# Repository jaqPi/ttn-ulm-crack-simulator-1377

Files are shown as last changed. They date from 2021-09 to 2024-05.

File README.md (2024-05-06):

# ttn-ulm-crack-simulator-1377

Experimental setup to benchmark various _VL6180X_ distance sensors. The VL6180X by _STMicroelectronics_ is a time-of-flight (ToF) distance and ambient light (ALS) sensor. It measures the time a laser takes from the sensor to a reflecting target and back to the sensor. It has an optimal operating range from 0 - 10 cm with a resolution of 1 mm (up to 60 cm with decreased resolution) and an accuracy of +/- 1 mm. For more details, please refer to the [datasheet](https://www.st.com/en/imaging-and-photonics-solutions/vl6180x.html#documentation).

## Terms

The following terms are used in the course of this document:

| Term | Explanation |
| --- | --- |
| Sensor | A term that that is used for several different things. In the strict definition, it describes that piece of hardware that is capable of measuring something. A sensor can measure one or many information about its environment. In our case, the actual sensor is the VL6180X.  It can measures a distance between itself and a reflector or obstacle. Furthermore, it is capable of measuring its ambient light conditions. **BUT:** In its broader meaning (especially in the context of Arduino-like microcontrollers), sensor does not only describe that sensing piece of hardware, but also the package of required electrical components that the sensor is connected to. That package is actually called **breakout board** but can also be referred to as sensor. In the following, we will refer to the breakout boards as sensor. |
| Breakout Board | Package of several required electrical components and the actual sensor. Shipped by an integrator (e.g., Pololu and Adafruit) |
| Actual Distance | Real distance between reflector and sensor |
| Measured Distance | Distance between sensor and reflector as measured by a sensor (will vary)
| Sample error | Each sensor is different. Therefore, measuring the exact thing with two sensors of the same type will result in more or less different measurements. The delta is called sample error. |
| Microcontroller (uC) | Same as _sensor_. In the strict sense, uC describes a processing unit. But in the broader (our) sense, uC describes a uC mounted on a board along with several electrical components required for an easy experimentation in the context of Arduino and Co. |

## Goal

Since the speed of light in a medium depends on the density of that medium, the measured distance varies depending on the following environmental factors:

1. Ambient Light
1. Temperature
1. Relative Humidity
1. Air Pressure

Moreover, the measured distance will be affected by further parameters we now, such as ambient light or voltage drift of the power supply, but even worse, there are some factors, we have not considered. Consequently, we assume, that it is more goal-oriented to collect many measurements under different environment conditions but with the same actual distance to derive a mathematical model. The model to be developed should take the environmental factors as listed above as well as the ambient light and measured distance as inputs, and should return a distance that is as close as possible the actual distance.

### Notes

1. We exclude the effect of the reflectance of the reflector. Regarding the datasheet, we chose a light grey piece of aluminum.
1. We further exclude the effect of a varying voltage. In our experiment, we use a power supply (instead of a battery) that always ensures the same voltage.
1. To minimize the impact of a broken sensor or sample error, we use two BME280 and four VL6180X from two different integrators.
1. The VL6180X sensor offers an accuracy of +/-1 mm and a resolution of 1 mm. Nevertheless, we assume, that with a sufficient amount of measurements, the measured distance converges to the actual distance.

## Setup

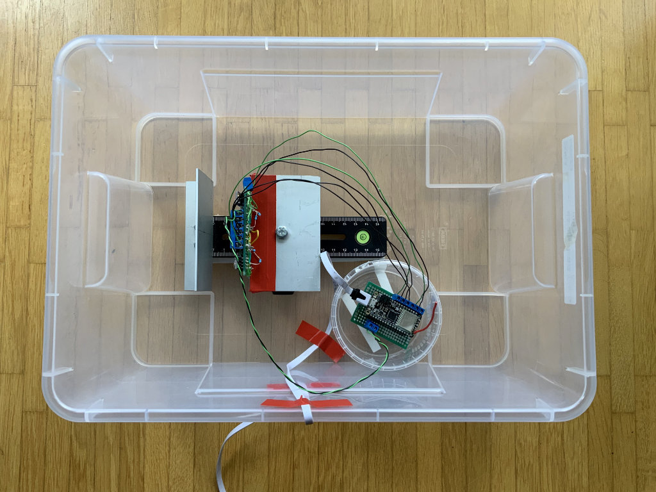
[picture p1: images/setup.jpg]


All sensors are soldered to a perfboard which is mounted on top of a rail slider. The slider can be fixed at any position along the rail. The reflector is screwed at one side of the rail and can not be moved.

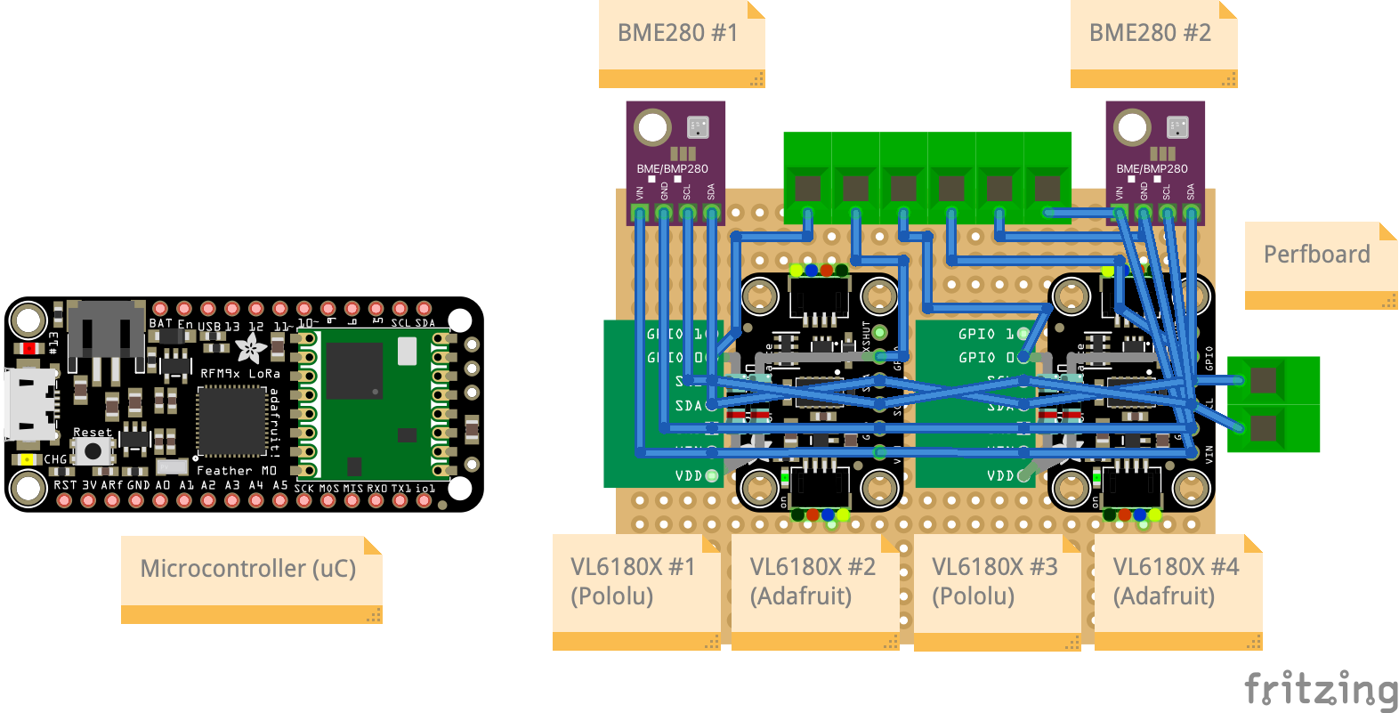
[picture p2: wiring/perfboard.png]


Sensors used and their sensing capabilities:

* 2x Pololu VL6180X (Distance, ambient light)
* 2x Adafruit VL6180X (distance, ambient light)
* 2x BME280 AliExpress (temperature, humidity, air pressure)

To start an experiment, the slider must be fixed to an arbitrary position.

## Program Flow

```mermaid
graph TD
    A[Start] --> B[Init Sensors];
    B --> |i=1|C[Measurement BME280 #i];
    C --> D{i < 2?};
    D --> |true / i+=1|C;
    D --> |false / d=1|E[Measurement VL6180X #i];
    E --> F{d < 4?};
    F --> |true / d+=1|E;
    F --> |false|G[Send data packets one by one];
    G --> H[Sleep]
    H --> |after 15 min / i=1|C;
```

As it can be seen, the measurements are taken sequentially. In other words, in theory, there may be a variation in the environment conditions between the single measurements. However, since a single measurement of a VL6180X takes around 5 s (BME280 < 1 s), we assume, that this variation can be ignored.

### Measurement

In case of the VL6180X measurements (distance and ambient light), each value is calculated on the basis of a series of 50 single measurements. Based on these 50 single values, we calculate the mean, standard derivation, and median at the uC.

In case of the BME280 measurements (temperature, air pressure, humidity), the values are read a single time from the sensor and not further processed.

### Data Transmission

Due to packet size restrictions by the LMiC library (max 53 Byte / Packet), the measured data is sent separately per sensor. The packets are queued and sent after all measurements are taken. Consequently, the transmission does not delay the measurements.

The sent data packets are received by a server and stored in a database.

## Payload Format

Per measurement iteration (consisting of two BME280 measurements and four VL6180X measurements) the uC sends five packets: a packet containing environmental data and four packets containing distance data.

## Environment Packet

First packet sent by uC.

| Name | Unit | Description |
| --- | --- | --- |
| temp1 | °C | Temperature measured by BME280 #1 |
| pressure1 | hPa | Atmospheric pressure measured by BME280 #1 |
| humidity1 | % | Relative humidity measured by BME280 #1 |
| temp2 | °C | Temperature measured by BME280 #2 |
| pressure2 | hPa | Atmospheric pressure measured by BME280 #2 |
| humidity2 | % | Relative humidity measured by BME280 #2 |

## Distance and Ambient Light (ALS) Packet

There are four VL6180X ToF distance sensors connected to the uC. Two manufactured by Pololu (#1+2) and two by Adafruit (#3+4).

| Name | Unit | Description |
| --- | --- | --- |
| meanDistanceX | mm | Mean of 50 x distance measurements |
| standardDeviationDistanceX | mm | Standard deviation of 50 x distance measurements |
| medianDistanceX | mm | Median of 50 x distance measurements |
| successfulMeasurementsDistance | - | If a single measurement times out, it is excluded from the values above. Remainder: a series consists of 50 measurements. Hence, the max value is 50. If value is below 50, value might not be reliable. |
| meanAmbientLightX | ? | Mean of 50 x ALS measurements |
| standardDeviationAmbientLightX | ? | Standard deviation of 50 x ALS measurements |
| medianAmbientLightX | ? | Median of 50 x ALS measurements |
| successfulMeasurementsAmbientLightX | - | If a single measurement times out, it is excluded from the values above. Remainder: a series consists of 50 measurements. Hence, the max value is 50. If value is below 50, value might not be reliable. |

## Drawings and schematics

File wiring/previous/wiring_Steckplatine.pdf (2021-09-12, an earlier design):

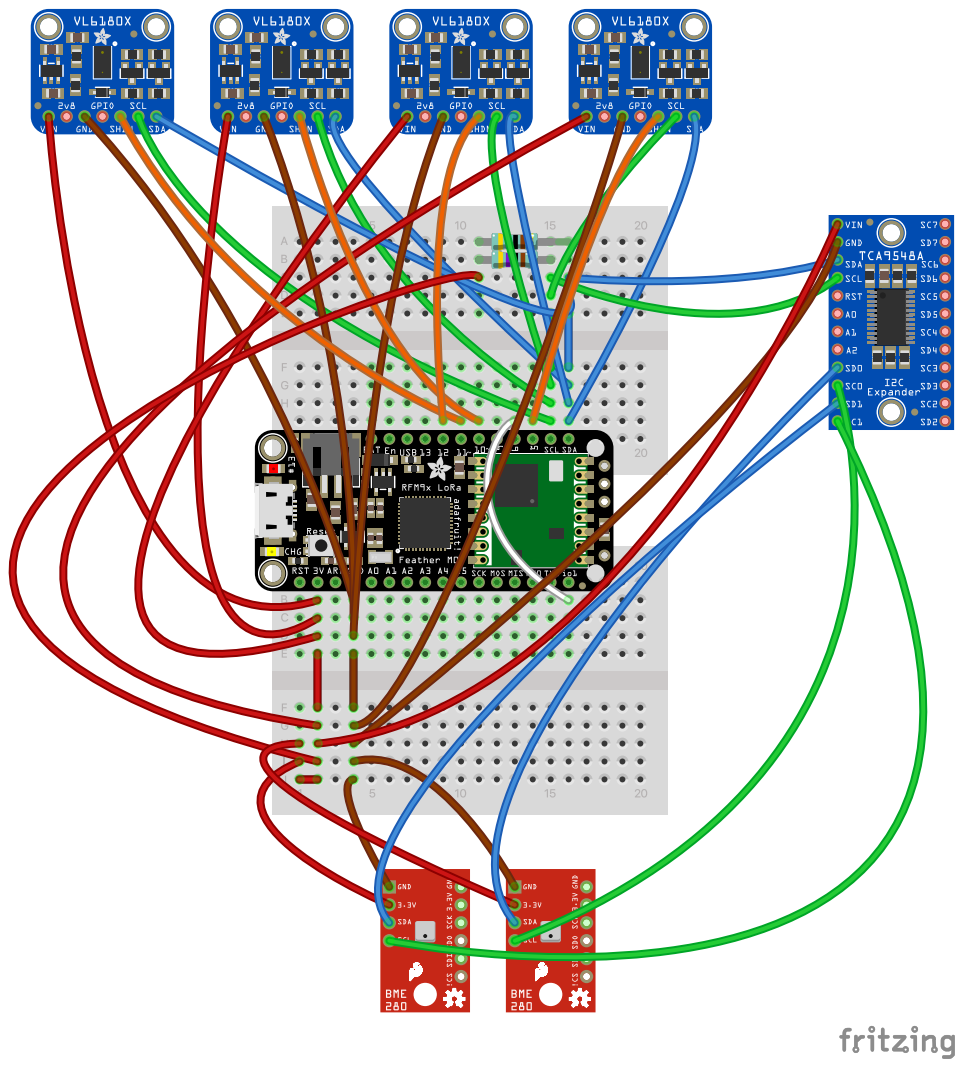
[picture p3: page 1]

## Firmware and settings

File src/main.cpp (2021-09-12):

/*
Code is based on the the OTAA example of the arduino-lmic library

 * Copyright (c) 2015 Thomas Telkamp and Matthijs Kooijman
 * Copyright (c) 2018 Terry Moore, MCCI

which is licensed under the MIT license
https://github.com/mcci-catena/arduino-lmic/blob/master/examples/ttn-otaa/ttn-otaa.ino
*/


#include <Arduino.h>
#include <SPI.h>
#include <Wire.h>
#include <VL6180X.h>
#include <Adafruit_Sensor.h>
#include <Adafruit_BME280.h>
#include "measurements.h"
#include "sensors.h"
#include <Statistics.h>
#include "arduino_lmic.h"
#include <hal/hal.h>
#include <Queue.h>

#include <Credentials.h> // TODO

VL6180X adafruitsensor1;
#define PIN_RESET_ADAFRUIT_1 10
VL6180X pololusensor1;
#define PIN_RESET_POLOLU_1 11
VL6180X adafruitsensor2;
#define PIN_RESET_ADAFRUIT_2 12
VL6180X pololusensor2;
#define PIN_RESET_POLOLU_2 5



const uint8_t numberOfMeasurements = 50; // max 255!

enum MESSAGE_TYPE {
  TEMPS,
  SENSOR1,
  SENSOR2,
  SENSOR3,
  SENSOR4,
  ERROR
};

enum ERROR_CODES {
  NO_RESPONSE_I2C_ADDRESS,
  DEFAULT_I2C,
  NO_RESPONSE_SENSOR,
  SENSOR_ERROR
};

typedef struct LoRaPacket {
    byte payload[20];
    uint8_t length;
} loRaPacket_t;

Queue<loRaPacket_t> queue = Queue<loRaPacket_t>(5);

Adafruit_BME280 bme1;
Adafruit_BME280 bme2;

// Initially the same config for all sensors
const SensorConfig configInterleaved = { INTERLEAVED, MANUAL, 30, 50, 500};
const SensorConfig configOneByOne = { ONE_BY_ONE, MANUAL, 30, 50, 500};

const TofSensor tofSensors[4] = {
  TofSensor { adafruitsensor1, configInterleaved, PIN_RESET_ADAFRUIT_1, 0x25 },
  TofSensor { pololusensor1,   configInterleaved, PIN_RESET_POLOLU_1,   0x26 },
  TofSensor { adafruitsensor2, configInterleaved, PIN_RESET_ADAFRUIT_2, 0x27 },
  TofSensor { pololusensor2,   configInterleaved, PIN_RESET_POLOLU_2,   0x28 }
};

const uint8_t numberOfSensors = sizeof(tofSensors) / sizeof(TofSensor);




void os_getArtEui (u1_t* buf) { memcpy_P(buf, APPEUI, 8);}
void os_getDevEui (u1_t* buf) { memcpy_P(buf, DEVEUI, 8);}
void os_getDevKey (u1_t* buf) {  memcpy_P(buf, APPKEY, 16);}



static osjob_t sendjob;

const unsigned TX_INTERVAL = 12*60; // in seconds


// Pin mapping
// Pin mapping for Adafruit Feather M0 LoRa
const lmic_pinmap lmic_pins = {
    .nss = 8,
    .rxtx = LMIC_UNUSED_PIN,
    .rst = 4,
    .dio = {3, 6, LMIC_UNUSED_PIN},
    .rxtx_rx_active = 0,
    .rssi_cal = 8,              // LBT cal for the Adafruit Feather M0 LoRa, in dB
    .spi_freq = 8000000,
};



void scanI2C() {
  Serial.println("I2C scanner. Scanning ...");
  byte count = 0;


  for (byte i = 1; i < 120; i++)
  {

    Wire.beginTransmission (i);
    if (Wire.endTransmission () == 0)
    {
      Serial.print("Found address: ");
      Serial.print(i);
      Serial.print(" (0x");
      Serial.print(i);
      Serial.println(")");
      count++;
      delay (1);  // maybe unneeded?
    } // end of good response
  } // end of for loop
  Serial.println("Done.");
  Serial.print("Found ");
  Serial.print(count);
  Serial.println(" device(s).");
}


/*
https://github.com/luetzel/VL6180x
https://forum.pololu.com/t/vl53l0x-maximum-sensors-on-i2c-arduino-bus/10845/20
https://github.com/pololu/vl53l0x-arduino/issues/1
*/


void do_send(osjob_t* j){
    // Check if there is not a current TX/RX job running
    if (LMIC.opmode & OP_TXRXPEND) {
        Serial.println(F("OP_TXRXPEND, not sending"));
    } else {

        // temp             -> 2 byte
        // pressure         -> 2 byte
        // humidity         -> 2 byte
        // ============================
         //              SUM:  6 byte
        //        x2 Sensors: 12 byte

        // distance         -> 2 byte
        // distanceSD       -> 2 byte
        // distanceMD       -> 2 byte
        // distanceSucc     -> 1 byte
        // ambientLight     -> 2 byte
        // ambientLightSD   -> 2 byte
        // ambientLightMD   -> 2 byte
        // ambietnLightSucc -> 1 byte
        // ============================
        //              SUM:  14 byte
        //       x4 Sensors:  56 byte

        loRaPacket_t envPacket;

        envPacket.payload[0] = TEMPS;


        // first BME
      
        // Only needed in forced mode. Force update of BME values
        bme1.takeForcedMeasurement();

        // temp
        int temp = round(bme1.readTemperature() * 100);
        envPacket.payload[1] = highByte(temp);
        envPacket.payload[2] = lowByte(temp);

        // pressure
        int pressure = round(bme1.readPressure()/100);
        envPacket.payload[3] = highByte(pressure);
        envPacket.payload[4] = lowByte(pressure);

        // humidity
        int humidity = round(bme1.readHumidity() * 100);
        envPacket.payload[5] = highByte(humidity);
        envPacket.payload[6] = lowByte(humidity);


      
        // Only needed in forced mode. Force update of BME values
        bme2.takeForcedMeasurement();

        // temp
        int temp2 = round(bme2.readTemperature() * 100);
        envPacket.payload[7] = highByte(temp2);
        envPacket.payload[8] = lowByte(temp2);

        // pressure
        int pressure2 = round(bme2.readPressure()/100);
        envPacket.payload[9] = highByte(pressure2);
        envPacket.payload[10] = lowByte(pressure2);

        // humidity
        int humidity2 = round(bme2.readHumidity() * 100);
        envPacket.payload[11] = highByte(humidity2);
        envPacket.payload[12] = lowByte(humidity2);

        envPacket.length = 13;
        queue.push(envPacket);


        // ToF-Sensors
        for (uint8_t i = 0; i < numberOfSensors; i++)
        {
          loRaPacket_t distancePacket;
          
          // error handling PRE measurement

          // is sensor reachable?
          Wire.beginTransmission(tofSensors[i].i2cAddress);
          uint8_t i2cStatus = Wire.endTransmission();
          if(i2cStatus != 0) {
              // the sensor is not reachable under its assigned address.
              // check for sensor's factory default address:

              Wire.beginTransmission(0x29);
              if(Wire.endTransmission() == 0) {
                // sensor was somehow resettet to its default i2c address
                distancePacket.payload[0] = ERROR;
                distancePacket.payload[1] = i + 1; // sensor number
                distancePacket.payload[2] = DEFAULT_I2C;
                distancePacket.length = 3;
                queue.push(distancePacket);
                continue;
              }
              else {
                // sensor is gone :-(
                distancePacket.payload[0] = ERROR;
                distancePacket.payload[1] = i + 1; // sensor number
                distancePacket.payload[2] = NO_RESPONSE_I2C_ADDRESS;
                distancePacket.payload[3] = i2cStatus;
                distancePacket.length = 4;
                queue.push(distancePacket);
                continue;
              }
          }

          // is sensor present?
          if(tofSensors[i].sensor.readReg(VL6180X::IDENTIFICATION__MODEL_ID) != 0xB4) {
            distancePacket.payload[0] = ERROR;
            distancePacket.payload[1] = i + 1; // sensor number
            distancePacket.payload[2] = NO_RESPONSE_SENSOR;
            distancePacket.length = 3;
            queue.push(distancePacket);
            continue;
          }
          
          measurement_t currentMeasurement = measureDistanceAndAmbientLight(&tofSensors[i], numberOfMeasurements);
          
          // error handling POST measurement
          if(currentMeasurement.distance.mean == 255.0) {
            byte errorCode = tofSensors[i].sensor.readReg(VL6180X::RESULT__RANGE_STATUS);
            distancePacket.payload[0] = ERROR;
            distancePacket.payload[1] = i + 1; // sensor number
            distancePacket.payload[2] = SENSOR_ERROR;
            // Sensor Error Code Overview:
            // * https://www.st.com/resource/en/datasheet/vl6180x.pdf
            // 
            // Error Code Description
            // * https://www.st.com/resource/en/design_tip/dm00114111-vl6180x-range-status-error-codes-explanation-stmicroelectronics.pdf
            // * https://www.st.com/content/ccc/resource/sales_and_marketing/presentation/product_presentation/cc/96/42/b5/56/60/4d/e0/VL6180X_API_IntegrationGuide.pdf/files/VL6180X_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
            distancePacket.payload[3] = errorCode;
            distancePacket.length = 4;
            queue.push(distancePacket);
            continue;
          }
          

          // number of Sensor
          distancePacket.payload[0] = i + 1;
          
          // encode config
          distancePacket.payload[1] = 0;
          if(tofSensors[i].config.calibrationMode == AUTO) {
            distancePacket.payload[1] |= 1 << 0;
          }

          if(tofSensors[i].config.measureMode == ONE_BY_ONE) {
            distancePacket.payload[1] |= 1 << 1;
          }

          
          // distance
          int meanDistance = round(currentMeasurement.distance.mean * 100);
          distancePacket.payload[2] = highByte(meanDistance);
          distancePacket.payload[3] = lowByte(meanDistance);

          int standardDeviationDistance = round(currentMeasurement.distance.standardDeviation * 100);
          distancePacket.payload[4] = highByte(standardDeviationDistance);
          distancePacket.payload[5] = lowByte(standardDeviationDistance);

          int medianDistance = round(currentMeasurement.distance.median * 100);
          distancePacket.payload[6] = highByte(medianDistance);
          distancePacket.payload[7] = lowByte(medianDistance);

          distancePacket.payload[8] = currentMeasurement.successfulMeasurementsDistance;

          // ambientLight
          int meanAmbientLight = round(currentMeasurement.light.mean * 100);
          distancePacket.payload[9] = highByte(meanAmbientLight);
          distancePacket.payload[10] = lowByte(meanAmbientLight);

          int standardDeviationAmbientLight = round(currentMeasurement.light.standardDeviation * 100);
          distancePacket.payload[11] = highByte(standardDeviationAmbientLight);
          distancePacket.payload[12] = lowByte(standardDeviationAmbientLight);

          int medianLight = round(currentMeasurement.light.median * 100);
          distancePacket.payload[13] = highByte(medianLight);
          distancePacket.payload[14] = lowByte(medianLight);

          distancePacket.payload[15] = currentMeasurement.successfulMeasurementsAmbientLight;

          distancePacket.length = 16;
          queue.push(distancePacket);
          // short delay
          delay(100);
        }


        loRaPacket_t packetToSend = queue.pop();
        LMIC_setTxData2(1, (uint8_t*)packetToSend.payload, packetToSend.length, 0);
        Serial.println(F("Pckt qd"));
    }
}

void onEvent (ev_t ev) {
    // print(os_getTime());
    // print(": ");
    Serial.print(os_getTime());
    Serial.println(": ");
    switch(ev) {
        case EV_SCAN_TIMEOUT:
            Serial.println(F("EV_SCAN_TIMEOUT"));
            break;
        case EV_BEACON_FOUND:
            Serial.println(F("EV_BEACON_FOUND"));
            break;
        case EV_BEACON_MISSED:
            Serial.println(F("EV_BEACON_MISSED"));
            break;
        case EV_BEACON_TRACKED:
            Serial.println(F("EV_BEACON_TRACKED"));
            break;
        case EV_JOINING:
            Serial.println(F("EV_JOINING"));
            break;
        case EV_JOINED:
            Serial.println(F("EV_JOINED"));
            break;
        /*
        || This event is defined but not used in the code. No
        || point in wasting codespace on it.
        ||
        || case EV_RFU1:
        ||     Serial.println(F("EV_RFU1"));
        ||     break;
        */
        case EV_JOIN_FAILED:
            Serial.println(F("EV_JOIN_FAILED"));
            break;
        case EV_REJOIN_FAILED:
            Serial.println(F("EV_REJOIN_FAILED"));
            break;
        case EV_TXCOMPLETE:
            Serial.println(F("EV_TXCOMPLETE (includes waiting for RX windows)"));
            if (LMIC.txrxFlags & TXRX_ACK)
              Serial.println(F("Received ack"));
            if (LMIC.dataLen) {
              Serial.println(F("Received "));
              Serial.println(LMIC.dataLen);
              Serial.println(F(" bytes of payload"));
            }

            if(queue.count() > 0) {
              loRaPacket_t packetToSend = queue.pop();
              LMIC_setTxData2(1, (uint8_t*)packetToSend.payload, packetToSend.length, 0);
              Serial.println(F("Pckt qd"));
            }
            else {
              // Schedule next transmission to be immediately after this
              os_setTimedCallback(&sendjob, os_getTime() + sec2osticks(TX_INTERVAL), do_send);
            }

            break;
        case EV_LOST_TSYNC:
            Serial.println(F("EV_LOST_TSYNC"));
            break;
        case EV_RESET:
            Serial.println(F("EV_RESET"));
            break;
        case EV_RXCOMPLETE:
            // data received in ping slot
            Serial.println(F("EV_RXCOMPLETE"));
            break;
        case EV_LINK_DEAD:
            Serial.println(F("EV_LINK_DEAD"));
            break;
        case EV_LINK_ALIVE:
            Serial.println(F("EV_LINK_ALIVE"));
            break;
        /*
        || This event is defined but not used in the code. No
        || point in wasting codespace on it.
        ||
        || case EV_SCAN_FOUND:
        ||    Serial.println(F("EV_SCAN_FOUND"));
        ||    break;
        */
        case EV_TXSTART:
            Serial.println(F("EV_TXSTART"));
            break;
        case EV_TXCANCELED:
            Serial.println(F("EV_TXCANCELED"));
            break;
        case EV_RXSTART:
            /* do not print anything -- it wrecks timing */
            break;
        case EV_JOIN_TXCOMPLETE:
            Serial.println(F("EV_JOIN_TXCOMPLETE: no JoinAccept"));
            break;
        default:
            Serial.print(F("Unknown event: "));
            Serial.println((unsigned) ev);
            break;
    }
}


void setup() {
    // Send shutdown signal to VL6180X sensors to be able to changer their I2C address
    for (uint8_t i = 0; i < numberOfSensors; i++)
    {
      pinMode(tofSensors[i].resetPin, OUTPUT);
      digitalWrite(tofSensors[i].resetPin, LOW);
    }    


    #ifdef DEBUG    
      Serial.begin(9600);
      while (!Serial);
    #endif
    Serial.println(F("Strtng"));

    delay(500);
    Wire.begin();

    // Wake up one sensor afther the other to change its I2C address
    // and configure it
    for (uint8_t i = 0; i < numberOfSensors; i++)
    {
      Serial.print("Configure ToF-Sensor #");
      Serial.print(i);
      Serial.print(": ");
      pinMode(tofSensors[i].resetPin, INPUT);
      delay(150);
      tofSensors[i].sensor.init();
      delay(100);
      tofSensors[i].sensor.setAddress(tofSensors[i].i2cAddress);
      Serial.print("I2C address set to ");
      Serial.print(tofSensors[i].sensor.getAddress());

      tofSensors[i].sensor.init();
      tofSensors[i].sensor.configureDefault();

      // Reduce range max convergence time and ALS integration
      // time to 30 ms and 50 ms, respectively, to allow 10 Hz
      // operation (as suggested by table "Interleaved mode
      // limits (10 Hz operation)" in the datasheet).
      tofSensors[i].sensor.writeReg(VL6180X::SYSRANGE__MAX_CONVERGENCE_TIME, tofSensors[i].config.rangeMaxConvergenceTime);
      tofSensors[i].sensor.writeReg16Bit(VL6180X::SYSALS__INTEGRATION_PERIOD, tofSensors[i].config.alsMaxIntegrationPeriod);
      tofSensors[i].sensor.setTimeout(tofSensors[i].config.timeout);

      // stop continuous mode if already active
      tofSensors[i].sensor.stopContinuous();
      // in case stopContinuous() triggered a single-shot
      // measurement, wait for it to complete
      delay(300);

      if(tofSensors[i].config.calibrationMode == MANUAL) {
        // disable auto calibrate (to do it manually before every series)
        tofSensors[i].sensor.writeReg(VL6180X::SYSRANGE__VHV_REPEAT_RATE, 0x00);    
        // calibrate single time (actually the sensor should have done it during start up)
        tofSensors[i].sensor.writeReg(VL6180X::SYSRANGE__VHV_RECALIBRATE, 0x01);   
      }

      Serial.println(", configuration completed");
    }

    

    // Setup BME280, use address 0x77 (default) or 0x76
    if (!bme1.begin(0x76)) {
      Serial.println(F("noBME1"));
      while (1);
    }

    // Setup BME280, use address 0x77 (default) or 0x76
    if (!bme2.begin(0x77)) {
      Serial.println(F("noBME2"));
      while (1);
    }

    
    // BME280 1
    bme1.setSampling(Adafruit_BME280::MODE_FORCED,
                    Adafruit_BME280::SAMPLING_X1, // temperature
                    Adafruit_BME280::SAMPLING_X1, // pressure
                    Adafruit_BME280::SAMPLING_X1, // humidity
                    Adafruit_BME280::FILTER_OFF   );


    
    bme2.setSampling(Adafruit_BME280::MODE_FORCED,
                    Adafruit_BME280::SAMPLING_X1, // temperature
                    Adafruit_BME280::SAMPLING_X1, // pressure
                    Adafruit_BME280::SAMPLING_X1, // humidity
                    Adafruit_BME280::FILTER_OFF   );

    scanI2C();

   // LMIC init
    os_init();
    // Reset the MAC state. Session and pending data transfers will be discarded.
    LMIC_reset();


    LMIC_setClockError(MAX_CLOCK_ERROR * 20 / 100);

    // Disable link check validation
    LMIC_setLinkCheckMode(0);

    // TTN uses SF9 for its RX2 window.
    LMIC.dn2Dr = DR_SF9;

    // Set data rate and transmit power for uplink
    LMIC_setDrTxpow(DR_SF7,14);

    // Start job
    do_send(&sendjob);
}

void loop()
{
  os_runloop_once();
}

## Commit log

2021-02-09 restructure, add sensor config to configure each sensor individually
2021-02-09 add calibration flag to sensor config
2021-02-13 add tests for statistics, move statistics to extra files, fix bugs in calculation of median
    [main.cpp]
2021-03-20 add LoRaWAN / TTN support, replace i2c multiplexer by second bme280 with another address
    [main.cpp]
2021-03-20 add sensor error detection
    [main.cpp]
2021-07-21 fix i2c addresses
2021-08-20 switch from ABP to OTAA
2021-09-12 new and more detailed readme file
    [lochrasterSensoren.fzz, wiring.fzz]
